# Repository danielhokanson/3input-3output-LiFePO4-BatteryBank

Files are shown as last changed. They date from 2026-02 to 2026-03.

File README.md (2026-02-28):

# Solar Battery Build Spec — Interactive Site

Interactive design & build specification for a consolidated LiFePO4 battery system built from salvaged Solariver solar pump units.

**Rev 3.1** — 4S3P (12× Grade B cells), three-shell serviceable enclosure, Salt Lake City outdoor installation.

## Quick Deploy to GitHub Pages

```bash
# Clone this repo (or just push the files)
git init
git add .
git commit -m "Initial commit — solar build spec Rev 3.1"
git branch -M main
git remote add origin git@github.com:danielhokanson/solar-build-spec.git
git push -u origin main
```

Then in the GitHub repo:
1. Go to **Settings → Pages**
2. Source: **Deploy from a branch**
3. Branch: **main**, folder: **/ (root)**
4. Click **Save**

Site will be live at `https://danielhokanson.github.io/solar-build-spec/` within a minute or two.

## Local Development

```bash
cd solar-build-spec
python3 -m http.server 8080
# Open http://localhost:8080
```

A local server is needed because the site fetches JSON data files via `fetch()`.

## Progress Tracking

Build progress (checkpoints, notes, measurements) is stored in your browser's `localStorage`. This means:
- Progress persists across browser sessions on the same device
- Progress does NOT sync between devices
- Use the **Export/Import** page to back up progress as a JSON file or transfer between devices

## Structure

```
solar-build-spec/
├── index.html          # Main shell
├── css/style.css       # Styling
├── js/app.js           # SPA router, rendering, progress tracking
├── data/
│   ├── spec.json       # Full specification content
│   └── progress.json   # Default progress template
└── README.md
```

## License

Specification content and site code for personal use.

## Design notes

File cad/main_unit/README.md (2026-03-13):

# Main Unit — CAD Roughout

Rev 3.2 | Updated 2026-03-12

## Overview

The **main unit** is the central control enclosure. It houses all power electronics
and the initial 4S2P cell bank (8 cells). Satellite units connect to it via external
leads and share the same BMS sense wires.

## What Goes Inside

| Zone | Contents |
|---|---|
| Battery zone | 8× Narada 105Ah cells (4S2P) — expandable via satellites |
| Electronics zone | 4× EPever Tracer 2210AN MPPT, 2× 4S 100A Smart BMS |
| Electronics zone | LEM HASS 100-S current sensor, distribution bus bars |
| Electronics zone | 2× 60A ATC fuse holder, terminal blocks, MC4 combiner |
| Thermal zone | 12V heater element, 120mm fan, STC-1000 thermostat |

## Cell Layout (4S2P, 8 cells)

Narada 105Ah measured dimensions: **129 × 36 × 256 mm** (L × W × H) + 4mm terminal protrusion

```
Front view — 4 cells across (series), 2 rows deep (parallel)

  [−][+][−][+]  ← row 1 (parallel string A)
  [−][+][−][+]  ← row 2 (parallel string B)

Width:  4 × 36mm + 6mm gaps + 8mm compression = ~158mm
Depth:  2 × 129mm + 10mm gap = ~268mm
Height: 256mm cells + 4mm terminals + 30mm busbars = ~290mm
```

Cells must be compressed: use threaded rod through compression plates
at each end of the 4-cell series stack.

## Electronics Zone Layout

```
┌──────────────────────────────────────────────────┐
│  [MPPT1]   [MPPT2]   │  Bus bar / fuses          │
│  [MPPT3]   [MPPT4]   │  2× BMS                   │
│  ← DIN rail ──────── │  Sensor / terminal blocks  │
│  Bottom: cable mgmt  │                             │
└──────────────────────────────────────────────────┘
```

EPever Tracer 2210AN: ~186 × 76 × 47 mm each.
2×2 grid on vertical mounting panel with 50mm clearance above each unit.

## Enclosure Dimensions (derived)

All values in mm. Shell 1 wall = 5mm, Shell 2 wall = 5mm, Foam = 30mm.

| Shell | Material | Wall | W × D × H |
|---|---|---|---|
| Interior space | — | — | 518 × 288 × 317 |
| Shell 2 (structural) | PETG | 5mm | 528 × 298 × 322 |
| Shell 1 (outer/boulder) | ASA | 5mm | 598 × 368 × 362 |
| Cap rim | ASA | — | 618 × 388 × 8 |
| Lid | ASA | — | 648 × 418 × 25 |

> Dimensions based on measured Narada 105Ah cells (129×36×256mm + 4mm terminals).

## Two-Shell Build

- **Shell 1 (ASA):** Outdoor UV-stable boulder aesthetic, 5mm wall, foam-bonded
- **Shell 2 (PETG):** Structural shell, 5mm wall, direct inner container for components
- **Foam:** 30mm PU two-part pour between Shell 1 and Shell 2
- **Cap rim:** Spans both shells; outer lip over S1, flange into foam zone, inner lip into S2; dual gaskets + M4 bolts
- **Lid:** 25mm thick ASA (20% infill = insulation), 20mm rain skirt with drip edge, bolts through cap rim

## Lid Design

The lid has no foam backing, so its thickness provides insulation via trapped air in
the infill pattern. Print at **20% infill** for optimal insulation-to-weight ratio.

| Parameter | Value |
|---|---|
| Lid thickness | 25mm (infill = insulation) |
| Lid overhang | 15mm beyond cap rim |
| Rain skirt | 20mm drop with drip edge groove |
| Drip edge | 3mm inset, 3mm deep, 2mm wide groove |
| Bolt pattern | Through-holes matching cap M4 pattern |
| Material | ASA (UV-stable, same as Shell 1) |

Shown in DXF Drawings 2, 3 (cross-sections), 8 (cap+lid profile), 9 (lid top view).

## Foam-Pressure Ribs

Ribs protrude into the foam cavity from Shell 1's inner surface and Shell 2's
outer surface. They interlock with cured foam to resist hydrostatic pressure
during the pour and improve long-term mechanical bond.

| Parameter | Value |
|---|---|
| Rib width | 3mm (along wall surface) |
| Rib height | 10mm (protrusion into foam cavity) |
| Rib spacing | 100mm center-to-center |
| First rib | ~50mm from base |
| Shown in | DXF Drawings 2 (front) and 3 (side) cross-sections |

Add ribs in Fusion as extruded features on the inner face of Shell 1 and
outer face of Shell 2 before the foam pour. Ribs do not change the 30mm
foam gap parameter -- they protrude into it.

## Integrated Spacers

Instead of separate spacer pieces, extrude standoff nubs directly from each
shell body into the foam gap. Shell 1 nubs point inward; Shell 2 nubs point
outward. They meet in the middle (~15mm each) to hold the 30mm gap during
the foam pour.

- Extrude from shell inner/outer faces at corner and mid-wall positions
- Same positions as the legacy spacer plan (4 corners + mid-walls, 2 vertical levels)
- No separate parts to align or slip during pour
- Foam bonds around and between nubs

## Conduit Penetrations (Rear Face)

| Conduit | Size | Count | Purpose |
|---|---|---|---|
| Solar MC4 pairs | 12mm | 4 | One per MPPT (3× Solariver + 1× Renogy) |
| Satellite leads | 16mm | 4 | One per satellite unit (future expansion) |
| Pump output | 10mm | 3 | 12V pump power (3× Solariver pumps) |
| Thermostat probe | 8mm | 1 | External temperature probe |
| Ethernet/comms | 8mm | 1 | Future monitoring |

### Conduit Sleeves

Each conduit hole gets a **5mm-wall tube** extruded from Shell 1 inward (or Shell 2
outward) spanning the ~30mm foam gap. This prevents foam from filling the conduit
openings during the pour.

- Sleeve OD = conduit ID + 2×5mm wall (e.g., 10mm conduit → 20mm OD sleeve)
- Sleeve length = foam gap (~30mm)
- Extrude as Fusion boss from the conduit hole perimeter
- Shell 1 and Shell 2 sleeves meet or overlap in the foam zone

## Foam Cavity Spacers (Legacy — see Integrated Spacers)

Spacers bridge the 30mm foam gap between Shell 1 and Shell 2, keeping
Shell 2 centered during the PU foam pour and preventing wall distortion.

| Type | Dimensions | Qty | Features |
|---|---|---|---|
| Corner spacer | L-shape 30×30×25mm, wall 12mm | 8 (4 corners × 2 levels) | M4 through-bolt clamp hole |
| Mid-wall spacer | 30×30×25mm block | 20 (10 positions × 2 levels) | Friction fit, foam bonds around |

Placed at two vertical levels (Z1 ≈ 90mm, Z2 ≈ 196mm from Shell 2 base).
Material: PETG (same as Shell 2). Corner spacers accept M4 bolts through
Shell 1 + spacer + Shell 2 for clamping during pour — remove or cap after cure.

> **Note:** Integrated spacers (extruded from shell bodies) are preferred over
> separate spacer pieces. The legacy spacer scripts are retained for reference.

## Fillet / Chamfer

Edge treatments applied in Fusion after panel splitting:

| Edge | Treatment | Size |
|---|---|---|
| Shell 1 outer edges | Fillet (rounded) | R = 8mm |
| Shell 2 inner edges | Fillet (stress relief) | R = 5mm |
| Lid top edges | 45° chamfer | 3mm |

Apply fillets/chamfers in Fusion using **Modify > Fillet** or **Modify > Chamfer**
on each panel body after Split Body. This softens the boulder aesthetic and
improves printability (reduces overhang stress).

## Running the Scripts

```bash
cd cad/main_unit

# DXF profiles for Fusion import (9 drawings)
python generate_dxf.py

# Split guide SVGs (construction plane positions)
python generate_panels.py

# Spacer drawings (DXF + SVG) — legacy, see Integrated Spacers
python generate_spacers.py
```

Outputs go to `cad/main_unit/dxf/`, `cad/main_unit/guides/`, and `cad/main_unit/spacers/`.

## Panel Identification

Each panel gets a 0.5mm raised ID embossed on its **inner face** during Fusion modeling.
This prevents mix-ups during assembly of 52 panels.

**Format:** `S{shell}-{face}-{##}`

| Code | Meaning |
|---|---|
| `S1` / `S2` | Shell number |
| `F` / `B` / `L` / `R` / `T` | Face: Front, Back, Left, Right, Top |
| `01`–`99` | Sequential panel number within that face |

**Examples:** `S1-F-01`, `S1-R-03`, `S2-B-02`, `S2-T-01`

**Fusion steps:**
1. After Split Body, select each panel's inner face
2. Create Sketch > Text (monospace font, ~8mm height)
3. Extrude text **0.5mm outward** from inner surface (Join to panel body)
4. Inner face placement keeps IDs hidden from exterior boulder surface

## Fusion Workflow

1. Import DXFs via **Insert > Insert DXF** onto appropriate sketch planes
2. Extrude to build monolithic shell bodies
3. Apply **Modify > Shell** command (Shell 1: 5mm wall, Shell 2: 5mm wall)
4. Add foam-pressure ribs (Extrude from inner/outer faces into foam cavity)
5. Add integrated spacer nubs (Extrude standoffs at corner/mid-wall positions)
6. Add conduit sleeves (Extrude 5mm-wall tubes around conduit holes, spanning foam gap)
7. Cut conduit holes (Extrude > Cut), positions per `4_rear_view.dxf`
8. Import split guides → create construction planes → **Modify > Split Body**
9. Add finger joints on each split face
10. Apply fillets (Shell 1: R8, Shell 2: R5) and chamfers (lid: 3mm)
11. Emboss panel IDs on inner faces (0.5mm raised text, see Panel Identification above)
12. Export panels as STL for Prusa Core One printing

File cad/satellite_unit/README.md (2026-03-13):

# Satellite Unit — CAD Roughout

Rev 3.2 | Updated 2026-03-12

## Overview

Each **satellite unit** is a self-contained battery expansion pod. It contains
one 4S cell string (4 cells in series) and thermal management only. All power
electronics stay in the main unit. The satellite connects via external leads:

- **Positive lead** (+) — goes to positive expansion bus in main unit
- **Negative lead** (−) — goes to negative expansion bus in main unit
- **BMS sense wire bundle** — 5 wires (4 cell tap + ground) to Smart BMS board
- **Thermal 12V feed** — heater strip + fan power from main unit

## What Goes Inside

| Zone | Contents |
|---|---|
| Battery zone | 4× Narada 105Ah cells (1× 4S string) |
| Battery zone | Compression plates, threaded rod, busbars |
| Thermal zone | 12V heater strip, 80mm fan, STC-1000 thermostat module |
| Conduit sleeve | Leads routed through embedded ASA sleeve to main unit |

**No BMS, no MPPT, no fuses, no distribution bus inside satellite.**

## Cell Layout (4S, 4 cells)

Narada 105Ah measured dimensions: **129 × 36 × 256 mm** (L × W × H) + 4mm terminal protrusion

```
Front view — 4 cells in a row (single 4S string)

  [−][+][−][+]   ← series string, 4 cells

Width:  4 × 36mm + 6mm gaps + 8mm compression = ~158mm
Depth:  1 × 129mm + margins = ~139mm
Height: 256mm cells + 4mm terminals + 30mm busbars = ~290mm
```

Cells compressed with threaded rod through aluminium compression plates.
BMS sense wires tap each cell terminal for SoC/cell-balance monitoring.

## Thermal Zone

```
  [CELLS][CELLS][CELLS][CELLS] | THERM ZONE
                                 ┌──────────┐
                                 │  FAN →   │
                                 │  HEATER  │
                                 │  THERM   │
                                 └──────────┘
```

- 80mm 12V fan (push/pull on end wall)
- Self-adhesive 24V silicone heater pad (via 12V→24V boost converter)
- STC-1000 thermostat module (controls heater + fan)
- Operating range: −26°C to +60°C

## Enclosure Dimensions (derived)

All values in mm. Shell 1 wall = 5mm, Shell 2 wall = 5mm, Foam = 30mm.
Two-shell construction: Shell 1 (ASA outer) + foam + Shell 2 (PETG structural/inner).
Shell 2 serves as both structural shell and direct inner container for components.

| Shell | Material | Wall | W × D × H |
|---|---|---|---|
| Shell 2 (structural/inner) | PETG | 5mm | 273 × 169 × 300 |
| Shell 1 (outer/boulder) | ASA | 5mm | 343 × 239 × 340 |
| Cap rim | ASA | — | 363 × 259 × 8 |
| Lid | ASA | — | 393 × 289 × 25 |

> Dimensions based on measured Narada 105Ah cells (129×36×256mm + 4mm terminals).

## Two-Shell Build

- **Shell 1 (ASA):** Outdoor UV-stable boulder aesthetic, 5mm wall
- **Shell 2 (PETG):** Structural shell, 5mm wall, direct inner container
- **Foam:** 30mm PU two-part pour between Shell 1 and Shell 2
- **Cap rim:** Spans both shells; outer lip over S1, flange into foam zone, inner lip into S2; dual gaskets + M4 bolts
- **Lid:** 25mm thick ASA (20% infill = insulation), 20mm rain skirt with drip edge, bolts through cap rim

## Lid Design

The lid has no foam backing, so its thickness provides insulation via trapped air in
the infill pattern. Print at **20% infill** for optimal insulation-to-weight ratio.

| Parameter | Value |
|---|---|
| Lid thickness | 25mm (infill = insulation) |
| Lid overhang | 15mm beyond cap rim |
| Rain skirt | 20mm drop with drip edge groove |
| Drip edge | 3mm inset, 3mm deep, 2mm wide groove |
| Bolt pattern | Through-holes matching cap M4 pattern |
| Material | ASA (UV-stable, same as Shell 1) |

Shown in DXF Drawings 2, 3 (cross-sections), 8 (cap+lid profile), 9 (lid top view).

## Foam-Pressure Ribs

Ribs protrude into the foam cavity from Shell 1's inner surface and Shell 2's
outer surface. They interlock with cured foam to resist hydrostatic pressure
during the pour and improve long-term mechanical bond.

| Parameter | Value |
|---|---|
| Rib width | 3mm (along wall surface) |
| Rib height | 10mm (protrusion into foam cavity) |
| Rib spacing | 100mm center-to-center |
| First rib | ~50mm from base |
| Shown in | DXF Drawings 2 (front) and 3 (side) cross-sections |

## Integrated Spacers

Instead of separate spacer pieces, extrude standoff nubs directly from each
shell body into the foam gap. Shell 1 nubs point inward; Shell 2 nubs point
outward. They meet in the middle (~15mm each) to hold the 30mm gap during
the foam pour.

- Extrude from shell inner/outer faces at corner and mid-wall positions
- Same positions as the legacy spacer plan (4 corners + mid-walls, 2 vertical levels)
- No separate parts to align or slip during pour
- Foam bonds around and between nubs

## Conduit Penetrations (Right Face)

| Conduit | Size | Count | Purpose |
|---|---|---|---|
| Battery leads | 16mm | 1 | Bundle: +/− power leads + BMS sense wires |
| Thermal 12V feed | 10mm | 1 | Heater + fan power from main unit |
| Thermostat probe | 8mm | 1 | External temperature probe |

### Conduit Sleeves

Each conduit hole gets a **5mm-wall tube** extruded from Shell 1 inward (or Shell 2
outward) spanning the ~30mm foam gap. This prevents foam from filling the conduit
openings during the pour.

- Sleeve OD = conduit ID + 2×5mm wall (e.g., 10mm conduit → 20mm OD sleeve)
- Sleeve length = foam gap (~30mm)
- Extrude as Fusion boss from the conduit hole perimeter
- Shell 1 and Shell 2 sleeves meet or overlap in the foam zone

Route satellite leads through conduit to the main unit's terminal block.

## Aesthetic

Boulder style matching main unit. ASA Shell 1 provides UV and thermal resistance.
Scale is intentionally compact vs the main unit.

## Foam Cavity Spacers (Legacy — see Integrated Spacers)

Spacers bridge the 30mm foam gap between Shell 1 and Shell 2, keeping
Shell 2 centered during the PU foam pour and preventing wall distortion.

| Type | Dimensions | Qty | Features |
|---|---|---|---|
| Corner spacer | L-shape 25×25×25mm, wall 12mm | 8 (4 corners × 2 levels) | M4 through-bolt clamp hole |
| Mid-wall spacer | 25×30×25mm block | 12 (6 positions × 2 levels) | Friction fit, foam bonds around |

Placed at two vertical levels (Z1 ≈ 90mm, Z2 ≈ 196mm from Shell 2 base).
Material: PETG. Corner spacers accept M4 bolts for clamping during pour.

> **Note:** Integrated spacers (extruded from shell bodies) are preferred over
> separate spacer pieces. The legacy spacer scripts are retained for reference.

## Fillet / Chamfer

Edge treatments applied in Fusion after panel splitting:

| Edge | Treatment | Size |
|---|---|---|
| Shell 1 outer edges | Fillet (rounded) | R = 8mm |
| Shell 2 inner edges | Fillet (stress relief) | R = 5mm |
| Lid top edges | 45° chamfer | 3mm |

Apply fillets/chamfers in Fusion using **Modify > Fillet** or **Modify > Chamfer**
on each panel body after Split Body.

## Panel Identification

Each panel gets a 0.5mm raised ID embossed on its **inner face** during Fusion modeling.
This prevents mix-ups during assembly of 28 panels.

**Format:** `S{shell}-{face}-{##}`

| Code | Meaning |
|---|---|
| `S1` / `S2` | Shell number |
| `F` / `B` / `L` / `R` / `T` | Face: Front, Back, Left, Right, Top |
| `01`–`99` | Sequential panel number within that face |

**Examples:** `S1-F-01`, `S1-L-02`, `S2-R-03`, `S2-T-01`

**Fusion steps:**
1. After Split Body, select each panel's inner face
2. Create Sketch > Text (monospace font, ~8mm height)
3. Extrude text **0.5mm outward** from inner surface (Join to panel body)
4. Inner face placement keeps IDs hidden from exterior boulder surface

## Running the Scripts

```bash
cd cad/satellite_unit

# DXF profiles for Fusion import (9 drawings)
python generate_dxf.py

# Split guide SVGs
python generate_panels.py

# Spacer drawings (DXF + SVG) — legacy, see Integrated Spacers
python generate_spacers.py
```

Outputs go to `cad/satellite_unit/dxf/`, `cad/satellite_unit/guides/`, and `cad/satellite_unit/spacers/`.

## Fusion Workflow

1. Import DXFs via **Insert > Insert DXF** onto appropriate sketch planes
2. Extrude to build monolithic shell bodies
3. Apply **Modify > Shell** command (Shell 1: 5mm wall, Shell 2: 5mm wall)
4. Add foam-pressure ribs (Extrude from inner/outer faces into foam cavity)
5. Add integrated spacer nubs (Extrude standoffs at corner/mid-wall positions)
6. Add conduit sleeves (Extrude 5mm-wall tubes around conduit holes, spanning foam gap)
7. Cut conduit holes (Extrude > Cut), positions per `4_lead_exit_view.dxf`
8. Import split guides → create construction planes → **Modify > Split Body**
9. Add finger joints on each split face
10. Apply fillets (Shell 1: R8, Shell 2: R5) and chamfers (lid: 3mm)
11. Emboss panel IDs on inner faces (0.5mm raised text, see Panel Identification above)
12. Export panels as STL for Prusa Core One printing

## Expansion

Each satellite adds one 4S parallel string. Connect up to 4 satellites to
the main unit for 4S6P total (24 cells, ~6,450 Wh usable). BMS sense wire
bundles extend to each satellite unit's cell taps. Current satellites planned:

| Unit | Cells | Config | Location |
|---|---|---|---|
| Main unit | 8 | 4S2P | Main enclosure |
| Satellite 1 | 4 | +4S string | Adjacent to main |
| Satellite 2–4 | 4 each | +4S string | Future expansion |

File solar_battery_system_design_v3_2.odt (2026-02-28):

Consolidated Solar Battery System

Design & Build Specification — Rev 3.1

Solariver Salvage — Salt Lake City Outdoor Installation

Updated: 12× Grade B cells, 4S3P config, three-shell serviceable enclosure

# 1. System Overview

This specification covers the design and construction of a consolidated LiFePO4 battery system built from three salvaged Solariver solar pump units. All three pump controllers accept 12V DC input and are designed to operate directly from solar or battery — no boost converters are required. The system charges from three solar panel inputs (2× 40W, 1× 25W) via individual MPPT controllers and is housed in a custom 3D-printed enclosure styled as a landscape boulder for outdoor installation in Salt Lake City.

Parameter | Value
Battery chemistry | LiFePO4 (lithium iron phosphate)
Nominal bank voltage | 12.8V (4S)
Cell configuration | 4S3P (12× 200Ah Grade B cells)
Nominal bank capacity | ~7,680 Wh (600Ah effective)
Usable capacity (80% DoD) | ~6,144 Wh
Solar inputs | 2× 40W + 1× 25W (105W total, 18V panels)
DC outputs | 3× 12V regulated (one per pump controller)
Output fusing | 2× 5A (470 GPH pumps), 1× 3A (235 GPH pump)
Thermal range (operating) | −26°C to +49°C (−15°F to 120°F)
Thermal management | Active — thermostat-controlled heat + ventilation
Max thermal system draw | 20W
Design load | ~65W average (all pumps running)
Autonomy without charging | 66+ hours (2.7 days at worst case)
Installation | Salt Lake City, outdoors, freestanding boulder enclosure

# 2. Confirmed Solariver Hardware

Unit | Kit | Panel | Pump | Original Battery
Unit 1 | 470+ GPH Kit | 40W, 18V | 18V DC submersible, ~20–30W draw | 12V / 8,000 mAh (96 Wh)
Unit 2 | 470+ GPH Kit | 40W, 18V | 18V DC submersible, ~20–30W draw | 12V / 8,000 mAh (96 Wh)
Unit 3 | 235+ GPH Kit | 25W, 18V | 18V DC submersible, ~10–15W draw | 12V / 6,000 mAh (72 Wh)
Totals | — | 105W solar | ~50–75W combined draw | 264 Wh (replacing with new bank)

All three pump controllers are confirmed to operate without a battery, powered directly from the solar panel. This means they will accept any clean 12V supply without proprietary handshaking or pairing requirements. The consolidated 12.8V LiFePO4 bank is a direct drop-in replacement for all three original 12V battery packs, with approximately 23× the combined capacity.

# 3. Energy Balance & Autonomy

## 3.1 Daytime Solar Pass-Through

During daylight hours with solar available, the EPever MPPT controllers' load output terminals power the pump controllers directly from solar, bypassing the battery for the pump load. The battery only receives net surplus power after the pump load is satisfied.

Condition | Solar In | Load | Net | Notes
Full sun, all pumps | 105W | ~65W | +40W charging | Normal sunny day in SLC
50% cloud cover | ~52W | ~65W | −13W (battery) | Common afternoon cloud
Heavy overcast | ~15W | ~65W | −50W (battery) | Battery carries most load
Night / no sun | 0W | ~65W | −65W (battery) | Full battery draw

On a typical clear SLC day with 5.5 peak sun hours, solar harvests approximately 578 Wh net after powering the pumps.

## 3.2 24-Hour Energy Budget (Real Load)

Item | Power | Duration | Energy
Pumps — all three running (average) | 65W | 24 hrs | 1,560 Wh
Thermal system (worst case, continuous) | 20W | 24 hrs | 480 Wh
BMS + wiring losses (~10%) | — | — | 204 Wh
Total consumption (worst case) | — | — | 2,244 Wh
Solar offset — clear day (5.5 peak hrs) | — | — | −578 Wh
Net battery draw — clear day | — | — | 1,666 Wh
Net battery draw — fully cloudy day | — | — | 2,244 Wh

## 3.3 Autonomy Analysis

With 6,144 Wh usable capacity (7,680 Wh nominal at 80% DoD):

- Fully cloudy days: 6,144 ÷ 2,244 = 2.7 days autonomy — significantly exceeds 24-hour target
- With solar on a clear day: net draw of 1,666 Wh leaves 4,478 Wh reserve after 24 hours
- Consecutive cloudy days: bank can sustain approximately 66 hours at real load without any solar input
- Real load of ~65W provides massive margin over original 100W design estimate
- The 4S3P upgrade provides 50% more capacity than the original 4S2P design for approximately 35% more cell cost

# 4. Electrical Architecture

## 4.1 Voltage Design

The 12.8V nominal LiFePO4 bank (4S configuration) directly matches all three pump controllers' 12V input requirements. No boost or step-up converters are needed anywhere in the system. The three 18V solar panels each feed a dedicated MPPT controller that charges the shared 12.8V bank. Outputs are three individually fused 12V taps directly from the battery bus.

Using three separate MPPT controllers rather than one multi-input unit provides panel isolation, redundancy, and straightforward integration with the salvaged Solariver panel wiring.

## 4.2 Solar Pass-Through (Load Output)

EPever Tracer MPPT controllers include dedicated load output terminals that intelligently manage solar pass-through. When the battery is full and solar is available, pump load is powered directly from solar. When solar is insufficient, the battery supplements or takes over automatically.

- Set load output mode to 'Normal' or 'Always On' in EPever settings
- Confirm load output current rating covers your pump draw (Tracer 2210AN: 20A load output — more than sufficient)
- Wire all three pump controller inputs to the load output terminals of their respective MPPT controllers

## 4.3 Wiring Architecture

Solar panels (3× 18V) → EPever MPPT controllers (3×, isolated inputs) → load output terminals → pump controllers (3× 12V). Simultaneously: MPPT charge outputs → 12.8V LiFePO4 bank with BMS → distribution bus → fused 12V taps → pump controllers (battery backup path). The BMS sits on the battery negative bus. An 80A ANL fuse sits on the battery positive bus as close to the cells as practical.

## 4.4 Output Fusing

Output | Device | Draw | Fuse | Wire Gauge
Output 1 | 470 GPH pump controller | ~3A | 5A blade fuse | 18 AWG minimum
Output 2 | 470 GPH pump controller | ~3A | 5A blade fuse | 18 AWG minimum
Output 3 | 235 GPH pump controller | ~1.5A | 3A blade fuse | 20 AWG minimum
Main bus | All loads + charging | 60A+ | 80A ANL fuse | 8 AWG

# 5. Battery Bank

## 5.1 Why LiFePO4

LiFePO4 is strongly preferred over LiPo for this application. LiPo cells perform poorly in cold temperatures, require more careful management to avoid thermal runaway, and have significantly shorter cycle lives (300–500 cycles vs 2,000+ for LiFePO4). For an unattended outdoor installation in Salt Lake City's climate extremes, LiFePO4's chemical stability, cold-temperature tolerance, and long service life make it the clear choice.

## 5.2 Why Grade B Cells

Grade B LiFePO4 cells are typically units that tested slightly below the manufacturer's rated capacity threshold (e.g., 185–195Ah on a 200Ah cell), were pulled from new but unsold battery packs, or have minor cosmetic defects that do not affect performance. For this application's moderate duty cycle (one partial daily cycle, rarely below 60% SOC on clear days), the practical difference from Grade A is negligible.

Purchasing 12 Grade B cells provides matching headroom — cells can be individually capacity-tested and matched into parallel groups of 3 within 2–3% capacity. The cost savings of approximately $280–360 vs Grade A makes this the optimal value choice. If all 12 cells match well, the pack can be built as 4S3P for 50% more capacity than the original 4S2P design.

## 5.3 Cell Configuration

12× 200Ah 3.2V LiFePO4 prismatic cells in 4S3P:

- 4S = 4 cells in series = 12.8V nominal (direct match for 12V pump controllers)
- 3P = 3 parallel strings = 600Ah effective
- Total bank: 12.8V × 600Ah = 7,680 Wh nominal
- Usable at 80% DoD: ~6,144 Wh — 2.7× the worst-case 24-hour draw

Recommended sources: EVE LF280K or CATL/CALB 200Ah prismatic cells, Grade B. Budget approximately $45–75 per cell ($540–900 for 12 cells). Cell dimensions approximately 174mm × 71mm × 207mm each; 4S3P stack occupies roughly 350mm × 215mm × 315mm.

## 5.4 Parallel Matching for 3P Strings

⚠ All three cells in each parallel group must be matched within 2–3% capacity and have similar internal resistance. Mismatched parallel cells cause uneven current distribution, accelerated aging, and potential thermal issues.

- Capacity-test all 12 cells individually with a full charge/discharge cycle
- Sort by measured capacity (highest to lowest)
- Group into 4 sets of 3, each set within 2–3% of each other
- Also compare internal resistance (IR) — cells in the same parallel group should be within 10–15% IR of each other
- If any cell cannot be matched into a group, set it aside as a spare
- If only 8–11 cells match well, fall back to 4S2P with the best 8 and keep the rest as spares

## 5.5 Critical Temperature Rules

⚠ These constraints are enforced by the BMS and thermostat system and must never be bypassed.

- Charging prohibited below 0°C (32°F) — causes lithium plating and permanent cell damage
- Discharging acceptable down to −20°C (−4°F) at reduced current
- Optimal operating range: 10°C to 35°C (50°F to 95°F)
- Maximum charge temperature: 45°C (113°F)
- BMS charge-inhibit port wired to temperature probe — enforces 0°C charge floor automatically

# 6. Thermal Management System

## 6.1 Salt Lake City Climate

SLC winters regularly reach −15°F (−26°C) and summers push 105°F (40°C+). The approach is insulation-first, with active thermostat-controlled heating and ventilation within the 20W power budget. The larger 4S3P battery provides even more thermal energy reserve for extended winter heating.

## 6.2 Heating (Winter)

A 12V PTC ceramic heater element (10–15W) inside the battery zone, wired to the thermostat heating relay. PTC elements are self-regulating — resistance increases as temperature rises, naturally throttling power draw.

- Heater ON below +5°C (41°F)
- Heater OFF at +10°C (50°F)
- BMS charge inhibit released only above 0°C (32°F)

## 6.3 Cooling (Summer)

Forced ventilation via a 12V brushless fan (3–5W) in the electronics outer zone. Reflective/light-colored enclosure exterior reduces solar heat gain. Note: the larger 4S3P cell mass provides more thermal inertia, which is beneficial — the pack heats and cools more slowly, damping temperature swings.

- Fan ON above +35°C (95°F) inside battery zone
- Fan OFF below +30°C (86°F)

## 6.4 Thermostat Setpoints

Function | Threshold | Action
Heating ON | +5°C (41°F) | PTC heater activates
Heating OFF | +10°C (50°F) | PTC heater deactivates
Cooling ON | +35°C (95°F) | Fan activates
Cooling OFF | +30°C (86°F) | Fan deactivates
Charge inhibit (BMS) | 0°C (32°F) | MPPT charge disconnected via BMS temp port

# 7. Enclosure Design

## 7.1 Overview — Three-Shell Serviceable Architecture

The enclosure uses a three-shell design that separates structural insulation from serviceable components. Every electrical component is removable and replaceable without destroying the enclosure. No component is permanently entombed in foam.

⚠ Design principle: Foam is only structural/thermal. No wires, no components, and no connections exist inside the foam cavity. Everything serviceable lives inside the inner service shell, accessed through insulated service panels.

## 7.2 Shell Layers (Outside → Inside)

- Shell 1 — Outer boulder: ASA filament, stone-textured. Cosmetic, weather barrier, structural outer wall. Permanently solvent-welded.
- Foam cavity (25–40mm): 2 lb closed-cell polyurethane pour foam between shells 1 and 2. Insulation + structural rigidity. Permanent — contains NO components or wiring.
- Shell 2 — Middle structural shell: ASA filament. Inner wall of foam cavity, mounting surface. Permanently solvent-welded to outer shell before foam pour.
- Shell 3 — Inner service shell: ASA filament, bolted (not welded) to shell 2. Houses ALL components. Accessible via removable insulated panels.

## 7.3 Cable Routing Through Foam Cavity

All cables between the exterior and the inner service shell pass through printed ASA conduit sleeves embedded in the foam cavity. Conduits are installed before the foam pour. Foam bonds around the outside of each conduit, but the interior remains hollow and clear. Wires can be pulled through at any time for replacement. PG cable glands thread into the outer end of each conduit for IP68 weather sealing.

## 7.4 Component Mounting (All Removable)

Every component mounts mechanically to the inner service shell or to DIN rail / mounting plates bolted to it. No component is glued, foamed, or permanently bonded. Cells sit on a compression cradle accessible through the battery access panel. Electronics mount on DIN rail or standoffs accessible through the electronics access panel.

## 7.5 Service Panels

Two removable access panels (battery zone and electronics zone) are printed ASA plates that sit in recessed frames with EPDM gasket seals. Behind each panel, a removable rigid foam insulation board (25mm XPS or polyiso) provides thermal isolation. The insulation is friction-fit and removed during service. Battery access panel opening: minimum 360mm × 220mm clear for cell stack removal. Electronics access panel: minimum 200mm × 180mm for MPPT controller removal.

## 7.5 Vent Ports

Two filtered vent ports on lower back face with printed ASA baffles preventing direct water ingress. Removable foam plugs available for winter to reduce heat loss.

## 7.6 Exterior Finish

Print in mid-gray ASA base. Apply stone-texture spray paint (Rust-Oleum Stone or similar) to match existing landscape features. UV-resistant clear topcoat. Light/reflective color is important — a dark boulder in SLC summer sun would significantly increase thermal load.

## 7.7 Mounting

Flat printed base with four heat-set M8 threaded inserts for optional anchor bolts. System weight approximately 28–32kg (cells alone ~24kg) — inherently stable freestanding.

# 8. Salvage from Solariver Units

Item | Action | Notes
Solar panels (40W × 2, 25W × 1) | Reuse all three | Test Voc and Isc before integration.
Pump controllers / timer boards | Reuse all three | Confirmed compatible with external 12V supply.
Pump units | Reuse all three | Powered by controllers; no changes.
Panel mounting hardware | Reuse | Brackets, tilt adjusters, fasteners.
Wiring harnesses and MC4 connectors | Reuse where possible | Inspect insulation; replace cracked runs.
Original batteries (12V SLA or LiPo) | Discard / recycle | Hazardous waste disposal.
Original PWM charge controllers | Discard | Replace with EPever MPPT units.

# 9. Recommended Build Sequence

Step 1 — Test salvaged panels: Measure Voc (open circuit) and Isc (short circuit) on each panel in direct sun. Confirm usable output on all three. Expected: ~21–22V Voc, 1–2.3A Isc depending on wattage.

Step 2 — Test pump controllers with external 12V: Before building anything, power each pump controller from a bench 12V supply and confirm normal pump operation.

Step 3 — Grade and test all 12 LiFePO4 cells: Capacity-test each cell individually. Match cells into parallel groups of 3 within 2–3% capacity and similar internal resistance. If fewer than 12 match, fall back to 4S2P with the best 8.

Step 4 — Build and bench-test battery pack: Wire 4S3P, connect BMS, verify cell voltages balance, confirm BMS protection triggers.

Step 5 — Build and bench-test full electronics stack: Wire EPever MPPT controllers, distribution bus, fuse block, and thermostat. Verify solar pass-through on load output terminals.

Step 6 — 24-hour bench endurance test: Run all three pump controllers at full load for 24 hours without solar input. Target: >3,900 Wh remaining (>50% SOC). The 4S3P pack should finish well above 60% SOC.

Step 7 — Design enclosure around confirmed component dimensions: Use actual measured 4S3P cell stack dimensions. Design boulder in CAD, segment for Prusa Core One bed size.

Step 8 — Print shells and conduit sleeves: Print all three shells, access panel covers, cable conduit sleeves, and vent conduit sleeves in ASA.

Step 9 — Assemble outer structure and pour foam: Solvent-weld shell 1 and shell 2 with conduit sleeves positioned between them. Verify all conduits are clear with pull wires. Pour foam into cavity. This is the only irreversible step — but no components live in the foam.

Step 10 — Install inner service shell and mount components: Bolt (not weld) inner service shell to middle shell. Mount ALL components mechanically — no glue, no foam. Route cables through conduit sleeves. Every component must be removable through an access panel.

Step 11 — Install insulation and close access panels: Cut rigid foam insulation boards for each panel opening. Friction-fit behind panels. Apply EPDM gasket. Bolt access panels closed. Install vent baffles.

Step 12 — Finish and install: Apply stone-texture paint and UV topcoat. Place in position, connect panels and pump controllers, verify operation. Confirm serviceability by opening and re-closing one access panel.

# 10. Full Component List

Component | Qty | Specification | Est. Cost
LiFePO4 prismatic cells | 12 | 200Ah 3.2V Grade B (EVE/CATL/CALB) | $540–900
4S LiFePO4 BMS | 1 | 60A+, temp cutoff, balance (JK BMS or Daly) | $40–80
EPever Tracer MPPT controller | 3 | 2210AN — 18V input, 12.8V LiFePO4, 20A load out | $35–55 ea.
Distribution bus bar | 1 | 12V pos + neg, 6+ terminals | $15–25
3-way blade fuse block | 1 | With 2× 5A + 1× 3A fuses | $8–15
80A ANL fuse + holder | 1 | Weatherproof, on positive bus | $10–18
STC-1000 thermostat controller | 1 | Dual stage, relay output, probe included | $12–18
PTC ceramic heater element | 1 | 12V, 10–15W, self-limiting | $8–15
12V brushless fan | 1 | 80–120mm, 3–5W | $8–12
8 AWG tinned marine wire | ~6m | Main bus runs (slightly longer for 3P) | $18–30
18–20 AWG tinned marine wire | ~10m | Branch runs to pump controllers | $10–18
PG cable glands (assorted) | 6–8 | PG9 and PG13.5 | $10–20
EPDM foam tape (gasket) | ~1m | 3–5mm closed-cell, self-adhesive | $5–10
Stainless M4 bolts + heat-set inserts | 8–10 sets | Service panel fasteners | $8–15
Stainless M8 inserts + anchor hardware | 4 sets | Base anchoring (optional) | $8–12
2-part pour foam kit | 1 | 2 lb closed-cell, 1–2 gallon kit | $20–35
ASA filament | 5–7 kg | Larger boulder for 4S3P stack | $80–175
Stone texture paint + UV topcoat | 1 set | Exterior masonry / stone spray, light color | $20–35
MC4 connectors (pairs) | 6 | For panel-to-controller connections | $10–18
Cell compression kit | 1 | Threaded rod, end plates for 4S3P stack | $15–30
Nickel-plated copper bus bars | 12 | Cell-to-cell connections (more for 3P) | $15–25

Estimated total (excluding salvaged panels, pump units, and controllers): $900–$1,450.

This represents a modest cost reduction from Rev 2 ($1,000–$1,550) despite 50% more cell capacity, thanks to Grade B cell pricing. The cell pack at $540–900 represents approximately 60% of total cost.

Items eliminated vs Rev 1: 2× 18V boost converters (no longer needed — all outputs are 12V native).

# 11. Safety Notes

⚠ Review ALL safety notes before beginning any electrical work. LiFePO4 cells at 200Ah can deliver thousands of amps into a short circuit.

- Never short cell terminals — even briefly. Cover all terminals with tape when not actively being connected.
- Always connect the BMS before connecting any load or charge source to the pack.
- Do not charge below 0°C — the thermostat/BMS interlock exists for this reason. Never bypass it.
- The foam pour (step 9) is irreversible — but no components live in the foam cavity. Verify all conduit sleeves are clear with pull wires before and after foam pour.
- Every component must remain removable through an access panel. Never glue, foam, or permanently bond any electrical component to the enclosure.
- Test thermostat, heater, and fan independently during step 10 before closing access panels in step 11.
- The ANL fuse on the positive bus is your primary fault protection. Install within 30cm of battery positive terminal.
- When disposing of old Solariver batteries, take to a battery recycling facility.
- With 3P parallel strings, ensure all three cells in each group are connected simultaneously. Never connect a charged cell in parallel with a discharged cell — the equalization current can exceed safe levels.

# 12. EPever MPPT Configuration

All three Tracer 2210AN controllers must be programmed with identical LiFePO4 battery settings. Configuration is unchanged from Rev 2 — the larger battery capacity does not affect charge controller settings since voltage is the same.

Parameter | Value | Notes
Battery Type | USER (LiFePO4) | Select 'USER' then set voltages below
Charging Limit Voltage | 14.4V | Absorption (3.60V/cell)
Float Voltage | 13.6V | 3.40V/cell — gentle maintenance float
Low Voltage Disconnect | 11.2V | Cut load (2.80V/cell)
Temperature Compensation | 0 mV/°C/2V | CRITICAL — disable for LiFePO4
Load Working Mode | Always ON | Or 'Light ON/OFF' for daytime-only
Equalization Duration | 0 min | Disable EQ cycling for LiFePO4
Boost Duration | 120 min | Time at absorption before float

⚠ Temperature Compensation must be set to 0 mV/°C/2V for LiFePO4. The default lead-acid compensation will overcharge LiFePO4 cells in cold weather, causing permanent damage.

Document prepared with Claude — Rev 3. Verify all electrical specifications against component datasheets before construction.

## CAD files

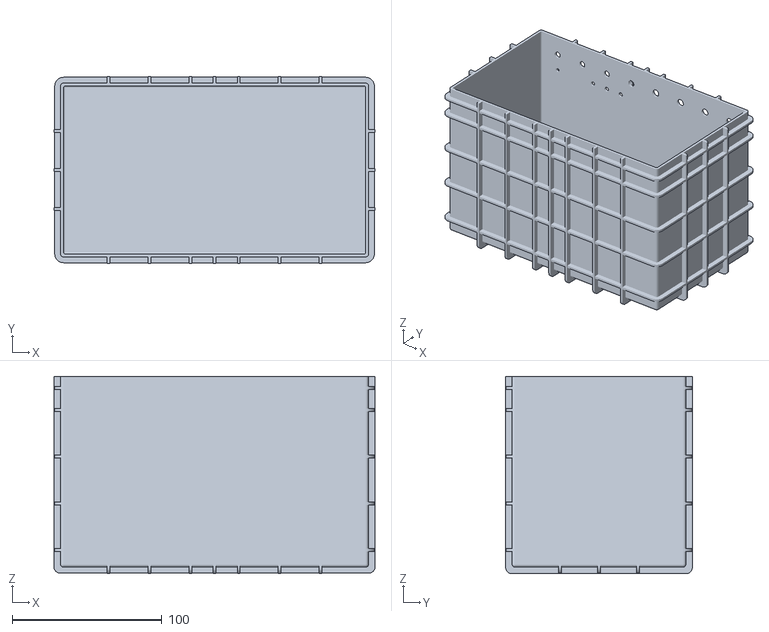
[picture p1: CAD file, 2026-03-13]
cad/main_unit/poc stl/Shell 2 (POC 39pct).stl
214.6 x 124.8 x 131.9

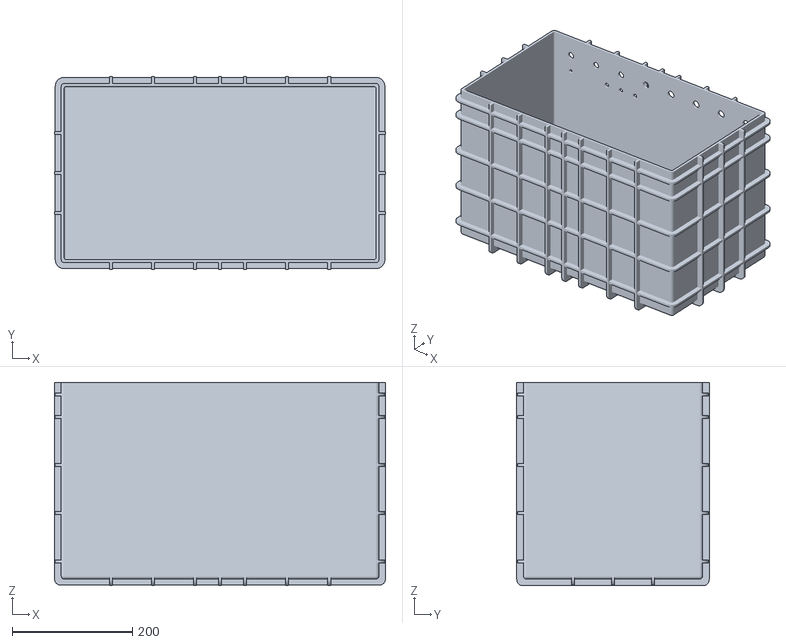
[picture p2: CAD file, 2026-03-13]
cad/main_unit/product stl/Shell 2.stl
550.2 x 320.0 x 338.0

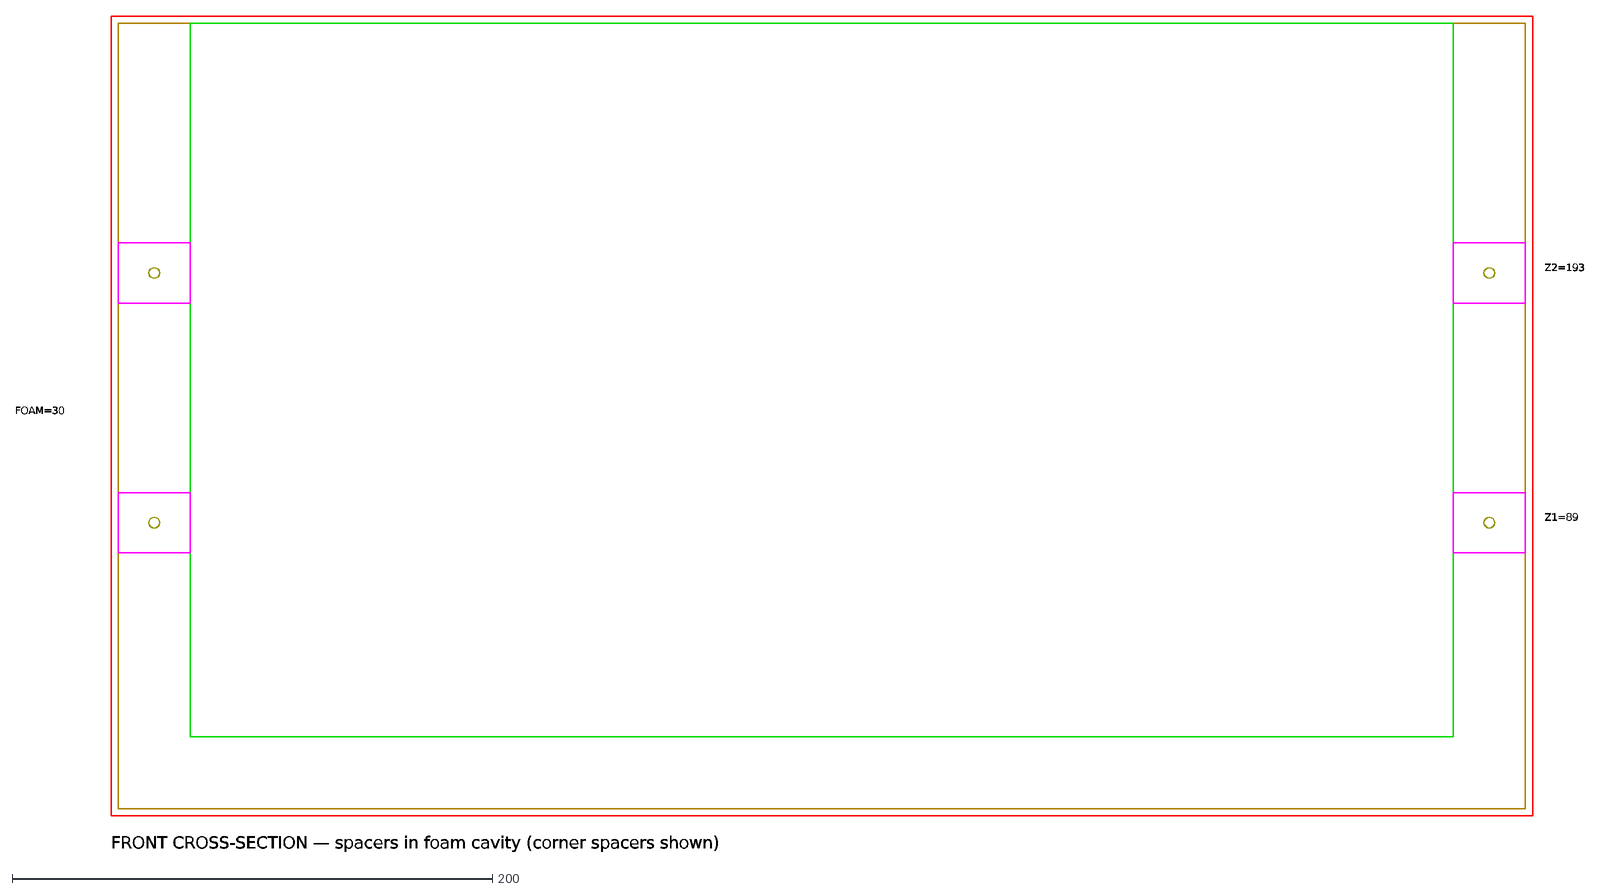
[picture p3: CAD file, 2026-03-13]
cad/main_unit/spacers/2_spacer_cross_section.dxf
Z1=89
Z2=193
FOAM=30
FRONT CROSS-SECTION — spacers in foam cavity (corner spacers shown)

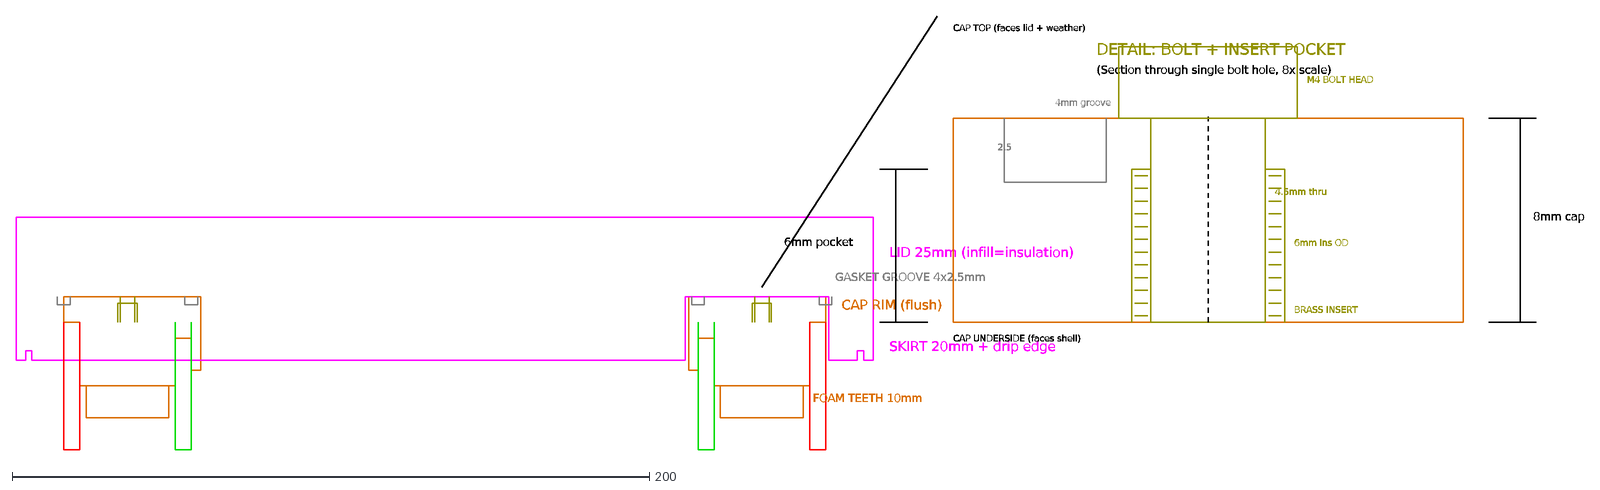
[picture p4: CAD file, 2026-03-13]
cad/satellite_unit/dxf/8_cap_profile.dxf
CAP RIM (flush)
LID 25mm (infill=insulation)
SKIRT 20mm + drip edge
FOAM TEETH 10mm
GASKET GROOVE 4x2.5mm
DETAIL: BOLT + INSERT POCKET
(Section through single bolt hole, 8x scale)
2.5
4mm groove
8mm cap
6mm pocket
4.5mm thru
6mm ins OD
CAP UNDERSIDE (faces shell)
CAP TOP (faces lid + weather)
BRASS INSERT
M4 BOLT HEAD

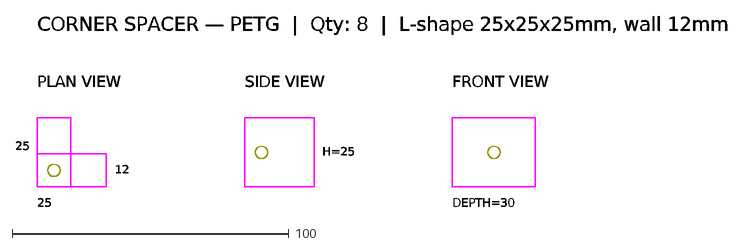
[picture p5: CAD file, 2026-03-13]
cad/satellite_unit/spacers/3_corner_spacer_detail.dxf
25
12
PLAN VIEW
H=25
SIDE VIEW
DEPTH=30
FRONT VIEW
CORNER SPACER — PETG | Qty: 8 | L-shape 25x25x25mm, wall 12mm

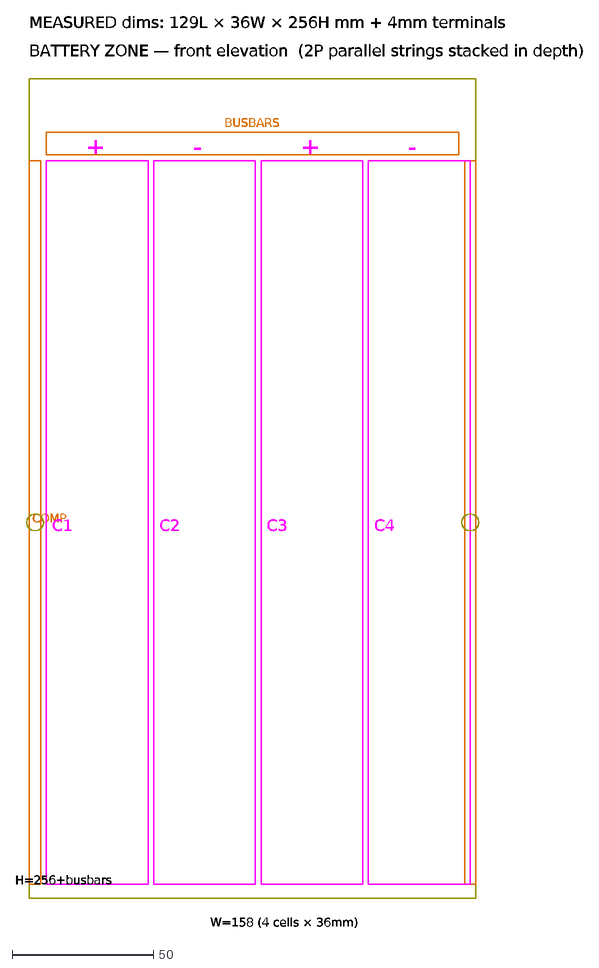
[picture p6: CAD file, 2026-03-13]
cad/main_unit/dxf/6_battery_zone_detail.dxf
COMP
+
C1
-
C2
C3
C4
BUSBARS
H=256+busbars
W=158 (4 cells × 36mm)
BATTERY ZONE — front elevation (2P parallel strings stacked in depth)
MEASURED dims: 129L × 36W × 256H mm + 4mm terminals

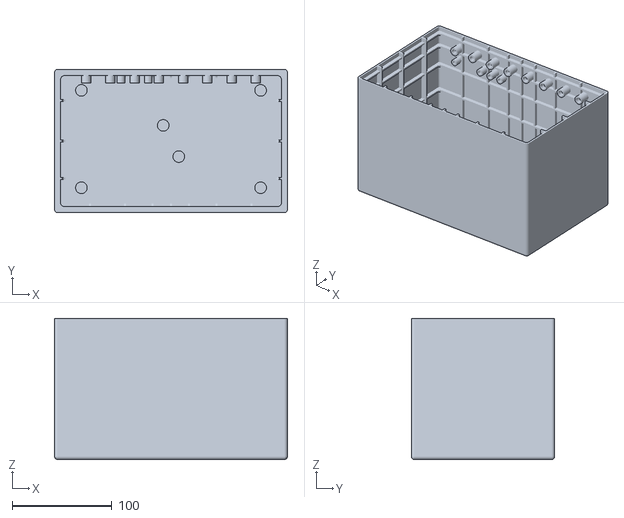
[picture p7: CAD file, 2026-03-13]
cad/main_unit/poc stl/Shell 1 (POC 39pct).stl
233.3 x 143.6 x 141.2

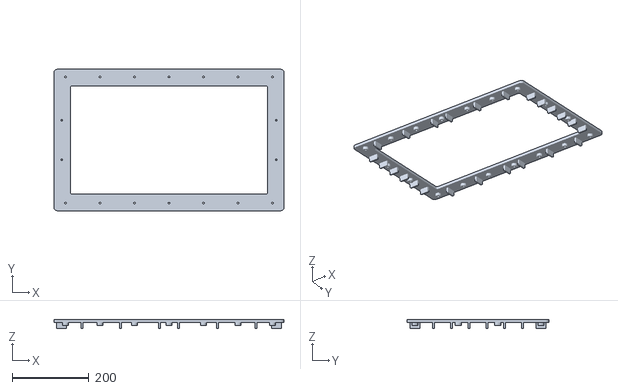
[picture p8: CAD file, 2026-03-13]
cad/main_unit/product stl/Cap.stl
598.0 x 368.0 x 23.0

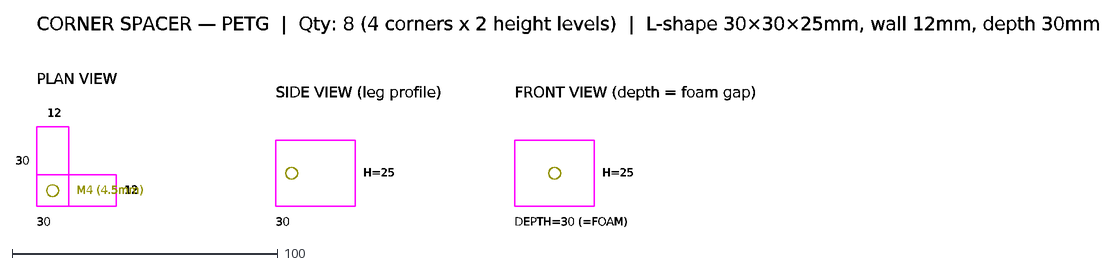
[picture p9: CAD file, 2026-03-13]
cad/main_unit/spacers/3_corner_spacer_detail.dxf
30
12
M4 (4.5mm)
PLAN VIEW
H=25
SIDE VIEW (leg profile)
DEPTH=30 (=FOAM)
FRONT VIEW (depth = foam gap)
CORNER SPACER — PETG | Qty: 8 (4 corners x 2 height levels) | L-shape 30×30×25mm, wall 12mm, depth 30mm

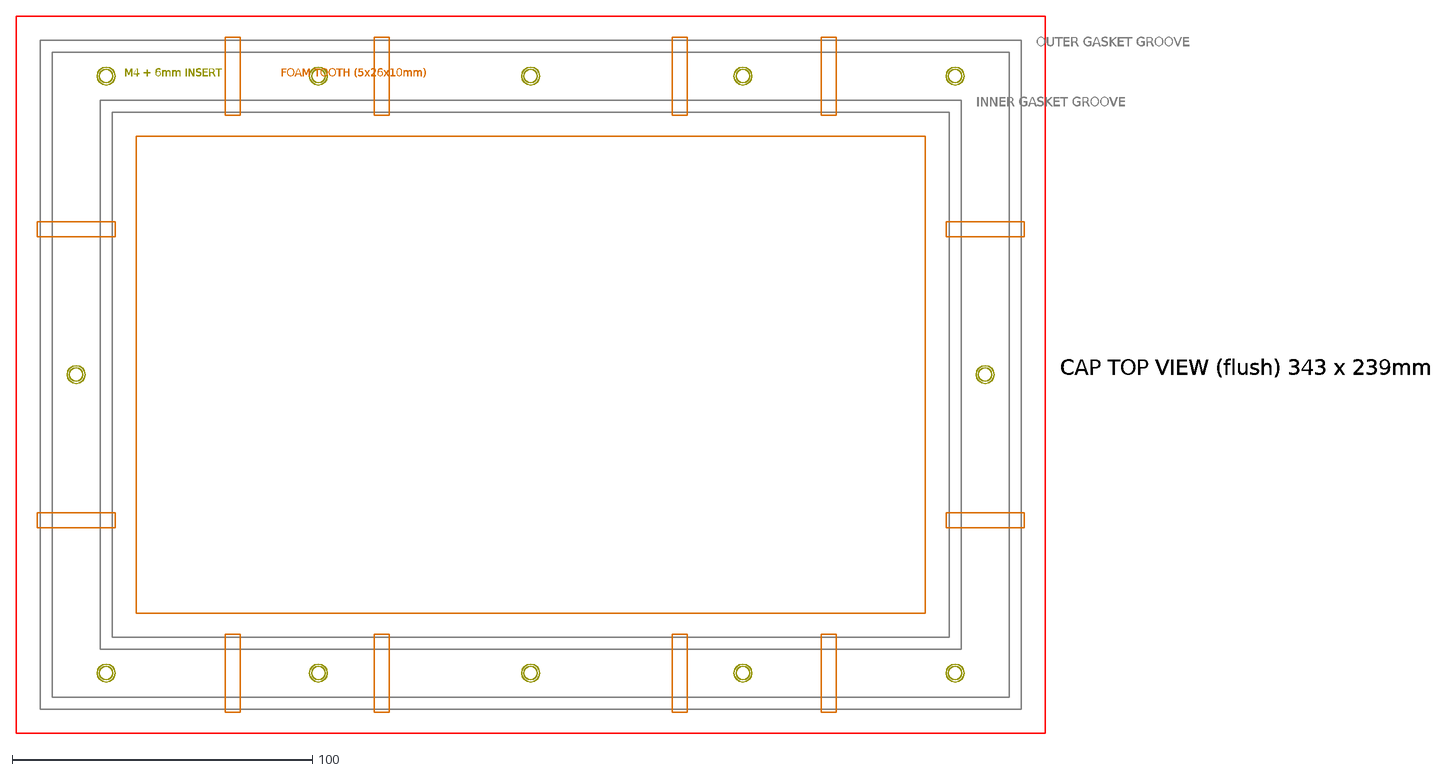
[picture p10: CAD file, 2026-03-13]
cad/satellite_unit/dxf/7_cap_top_view.dxf
CAP TOP VIEW (flush) 343 x 239mm
OUTER GASKET GROOVE
INNER GASKET GROOVE
M4 + 6mm INSERT
FOAM TOOTH (5x26x10mm)

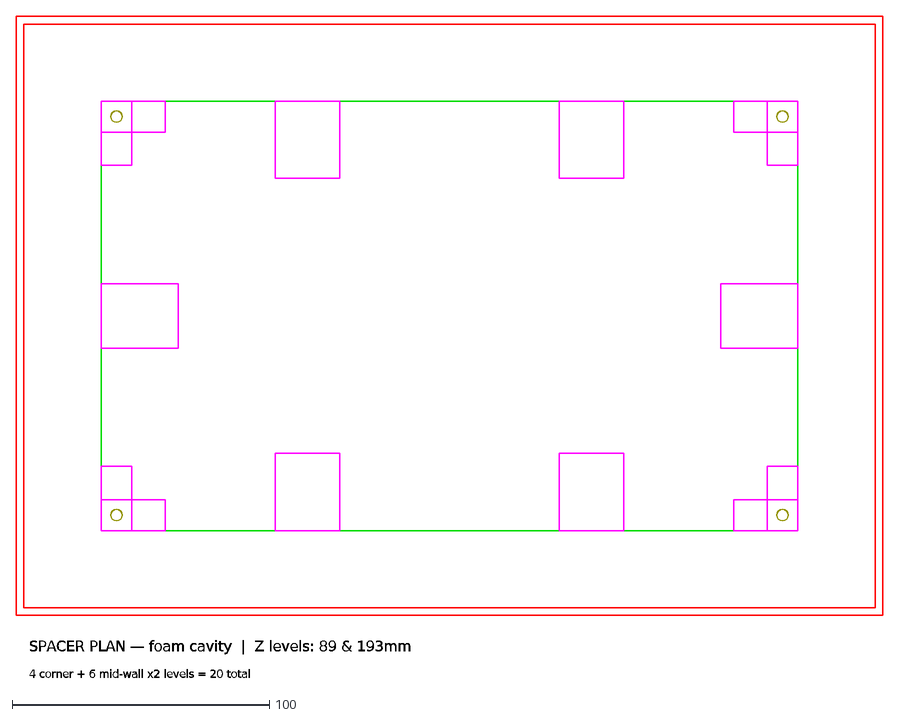
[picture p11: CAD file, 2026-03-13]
cad/satellite_unit/spacers/1_spacer_plan.dxf
SPACER PLAN — foam cavity | Z levels: 89 & 193mm
4 corner + 6 mid-wall x2 levels = 20 total

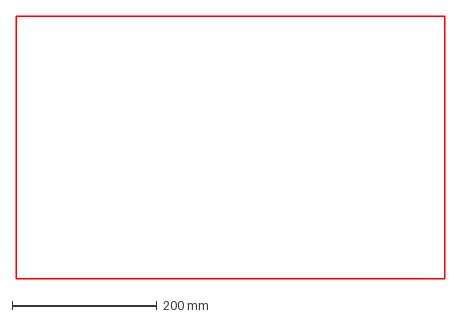
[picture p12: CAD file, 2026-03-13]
cad/main_unit/dxf/test_r2000.dxf
592.0 x 362.0 mm

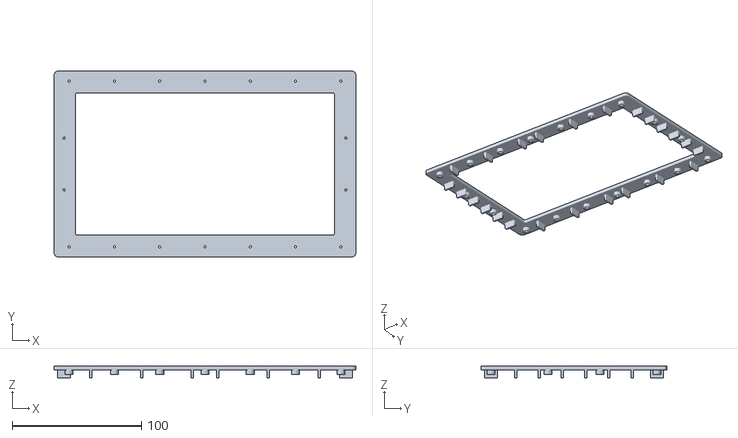
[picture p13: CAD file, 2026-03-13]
cad/main_unit/poc stl/Cap (POC 39pct).stl
233.3 x 143.6 x 8.97

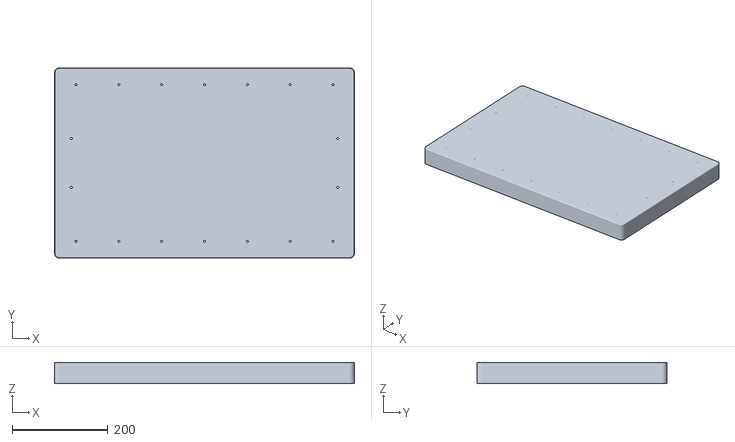
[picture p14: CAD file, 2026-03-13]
cad/main_unit/product stl/Lid.stl
628.0 x 398.0 x 45.0

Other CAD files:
cad/main_unit/dxf/8_cap_profile.dxf
cad/main_unit/spacers/4_midwall_spacer_detail.dxf
cad/satellite_unit/dxf/6_cell_layout_detail.dxf
cad/satellite_unit/spacers/2_spacer_cross_section.dxf
cad/main_unit/dxf/1_top_view.dxf
cad/main_unit/dxf/2_cross_section_front.dxf
cad/main_unit/dxf/3_cross_section_side.dxf
cad/main_unit/dxf/4_rear_view.dxf
cad/main_unit/dxf/5_zone_layout.dxf
cad/main_unit/dxf/7_cap_top_view.dxf
cad/main_unit/dxf/9_lid_top_view.dxf
cad/main_unit/dxf/test_minimal.dxf
cad/main_unit/dxf/test_r12_lines.dxf
cad/main_unit/dxf/test_r2010_units.dxf
cad/main_unit/dxf/test_raw.dxf
cad/main_unit/poc stl/Lid (POC 39pct).stl
cad/main_unit/product stl/Shell 1.stl
cad/main_unit/spacers/1_spacer_plan.dxf
cad/satellite_unit/dxf/1_top_view.dxf
cad/satellite_unit/dxf/2_cross_section_front.dxf
cad/satellite_unit/dxf/3_cross_section_side.dxf
cad/satellite_unit/dxf/4_lead_exit_view.dxf
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
